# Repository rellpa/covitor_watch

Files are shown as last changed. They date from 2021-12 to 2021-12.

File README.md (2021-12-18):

# 🔥 CoViTor Watch 🔥
### <i>#Final project of Embedded System Design</i>
- CoViToR Watch App created using Android Studio with Java

⌚⌚⌚⌚⌚

Smartwatch system, made for COVID-19 symptoms monitoring where you can monitor your current health condition such as temperature, oxygen saturation, and heart rate. So when there are any symptoms of COVID-19 you can take the appropriate action.

Stay healthy and keep wearing your mask!! 😷

<p align="left">
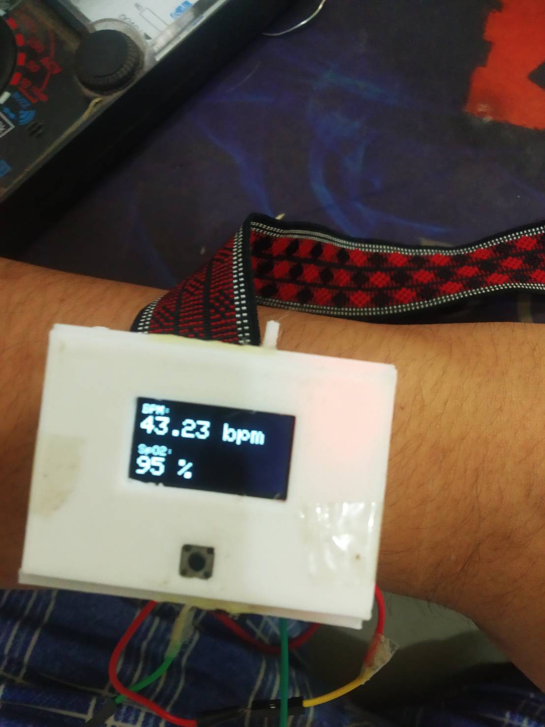
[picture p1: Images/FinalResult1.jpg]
  
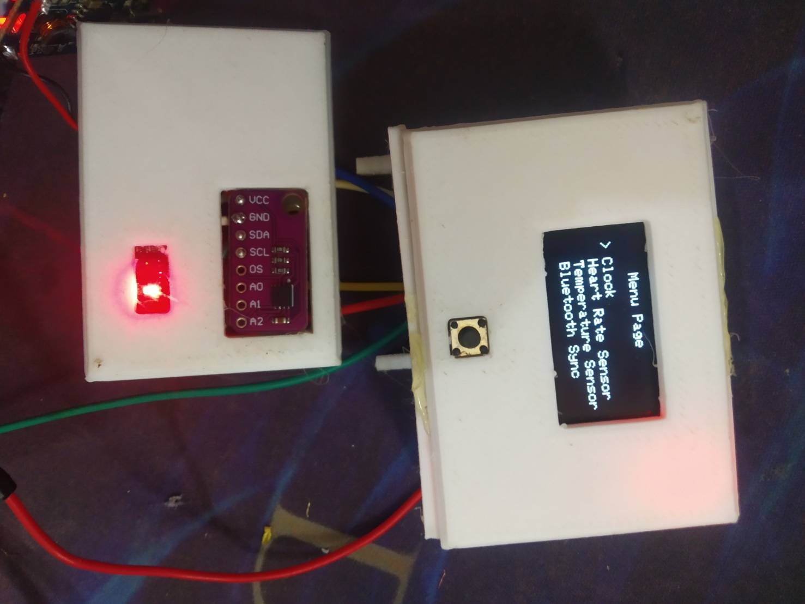
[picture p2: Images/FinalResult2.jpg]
  
</p>

#

## 🔌 How to make this embedded system.
### List of component
- Microcontroller Wemos D1 (NodeMCU ESP32 wifi+BL)
- Watch Sized SSD1306 0.96 inch OLED LCD I2C
- Enclosure Smartwatch 3D print
- A button
- Cables
- Battery 503030 3.7V mini 500mAh
- Charging controller TP4056
- 2.8cm / 28mm watch strap with 3cm spring bar
- MAX30205 Temperature Sensor 0°C to 50°C (Human Range)
- MAX30100 Heartrate and Oxymeter Sensor
- DS1307 + 24c32 Module IIC precision Real Time Clock(RTC) for Arduino (+CR2032 Battery)

Budget for component on december 2021 = Rp. 321.400 (~ US $22,34)

### Hardware Diagram
<p align="left">
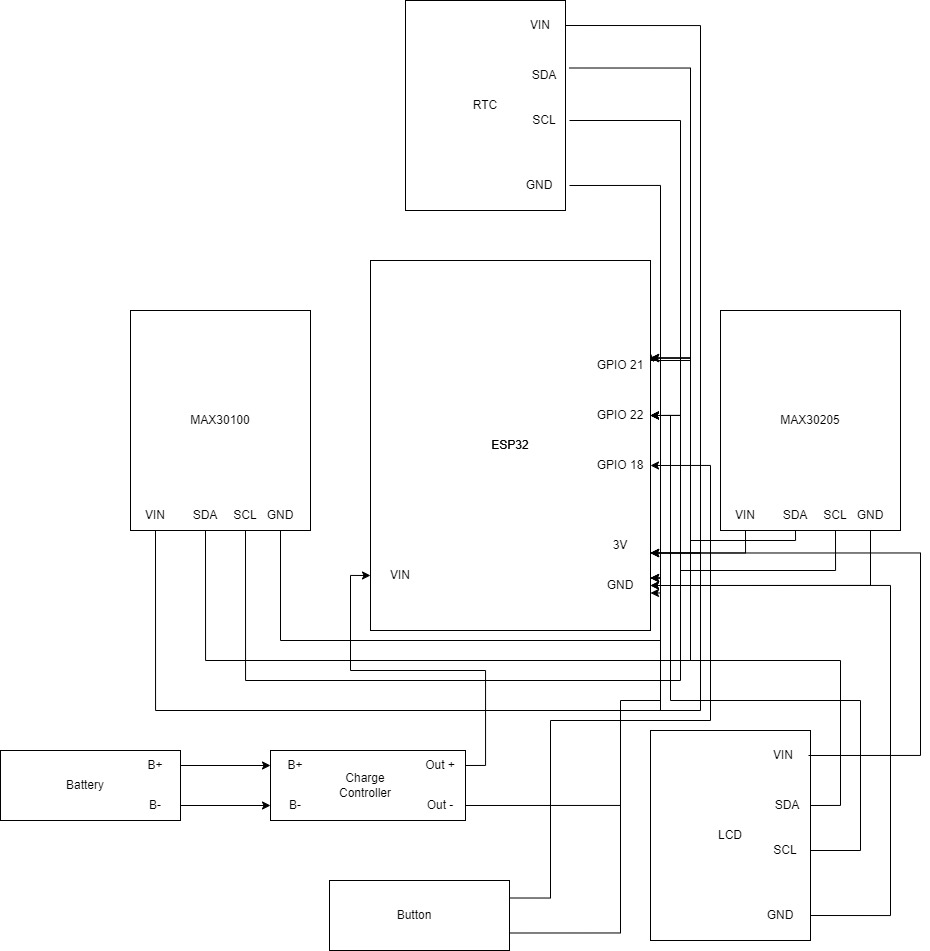
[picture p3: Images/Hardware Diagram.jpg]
  
</p>

- <i>I2C module (MAX30100, MAX30205, DS1307, SSD1306)</i>
- SCL -> GPIO 22 (ESP32)
- SDA -> GPIO 21 (ESP32)
- Vin -> 3.3V (ESP32)
- GND -> GND (ESP32)

### Architecture Diagram
<p align="left">
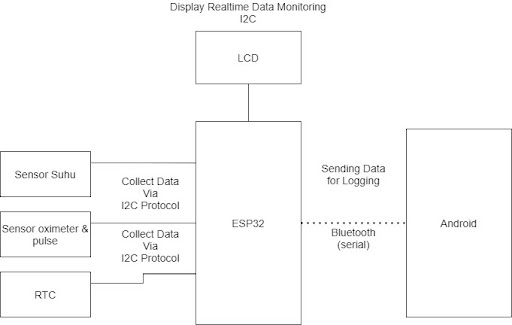
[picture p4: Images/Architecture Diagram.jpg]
  
</p>

### MVC
<p align="left">
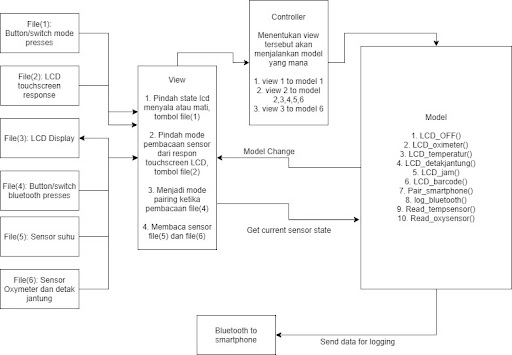
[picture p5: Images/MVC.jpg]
  
</p>

#

## 🤖 Arduino
We're using ESP32 Wemos D1 Mini

For some other controllers including controllers which are not ESP family, may need some more configuration.

How to use this code
- Install and open arduino IDE
- Install esp32 board family, using board manager
- Clone and open "CovitorWatch.ino"
- Flash to esp32 controller using available port
- Done

Features:
- Motion detector with one button
- Menu page
- Clock page
- Heart Rate, Blood Saturation, and Temparature readings page.
- Bluetooth Sync Mode
- QR code
- Blank screen for power saving

Library:
- BluetoothSerial
- Adafruit_GFX
- Adafruit_SSD1306
- RTClib
- MAX30100_PulseOximeter
- Protocentral_MAX30205
- OneButton

### <i>*How to use</i>
- double click to OK and go to menu page.
- triple click on any page to go QR code page.
- Long click on any page to go blank screen, use double click to exit blank screen mode.

### <i>*For improvement</i>
When using bluetooth serial, the heart rate and oximeter data are not updating because a problem. On ESP32, somehow the library of MAX30100 and bluetooth serial can't work together. This is because if you use a serial bluetooth module, it will slow down the looping time of the routine. The MAX30100 library is set to update data with a sampling frequency of 100Hz, so it should take less than 10ms to call this function. For that, use a newer module such as MAX30102, to get improvement functionality.

#

## 🚨 3D Enclosure
To create the 3D enclosure, we used 3D print Creality Ender-3 Pro
with printer settings:

- Slicer App: PrusaSlicer 2.3.1
- Print Setting: 0.28mm (use 0.16mm or 0.20mm for more tidy looks)
- Filament: PLA (please use ABS or something stronger than PLA if you want more rigid)
- Infill: 15%
- Supports: None
- Duration for all parts: 1 hour (0.28mm quality)

<i>*For watch strap, please using 28mm size with 30mm Spring Bar</i>

#

Full enclosure:
<p align="left">
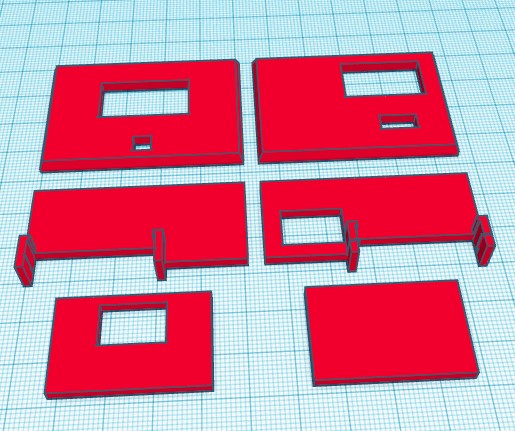
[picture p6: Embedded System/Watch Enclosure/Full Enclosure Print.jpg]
  
</p>

Component arrangement:
<p align="left">
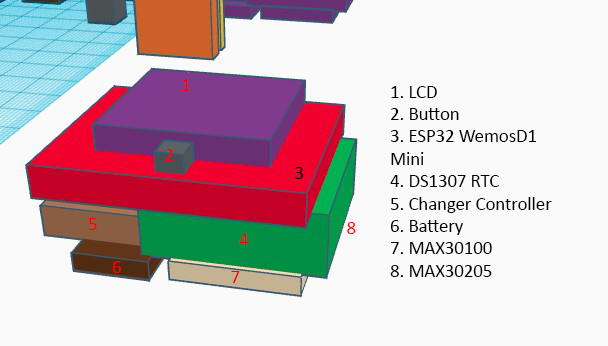
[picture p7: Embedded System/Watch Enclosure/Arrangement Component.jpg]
  
</p>

#

## 📱 CoViTor Watch APP
<i>!!This app created using android studio and java languange</i>

### How this app work?
In our embedded system (CoViTor Smartwatch), we use bluetooth serial (Bluetooth 2). So we can communicate using Bluetooth Socket from android. Basically, using bluetooth serial communication to an embedded system is to use an outputstream to send data and an inputstream to get data. We just need to manage how the two work together to form a useful application. For the monitoring sequence, we use a query method when needed so that the embedded system does not always send data. First the application will send a command that the embedded system knows what to send. After that the embedded system will send sensor data to the application, and the application will parse the byte data into strings or integers for further processing.

<p align="left">
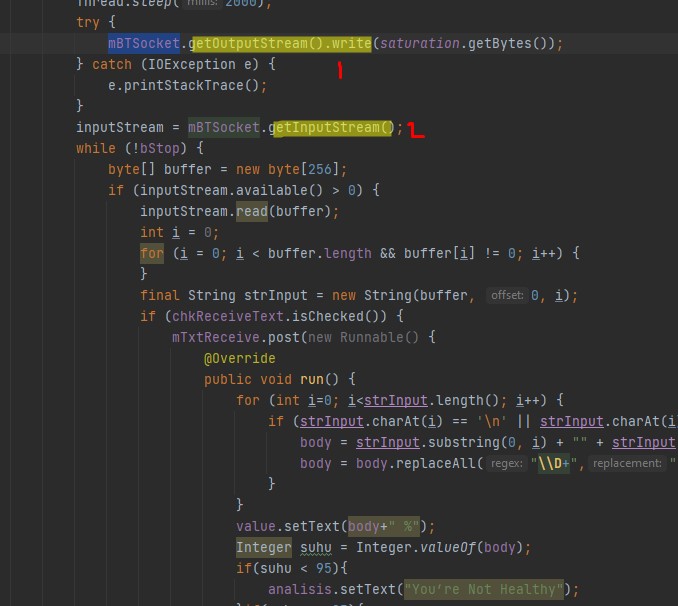
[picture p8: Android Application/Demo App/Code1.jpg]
  
</p>

### How to use this project ?
For demo purpose (if you use same firmware as this embbeded system) you can install APK app on your android phone.

If you want reverse engineering this project app:
1. Install android studio on your computer
2. Clone "CovitorWatchEmbedded" folder
3. Import that folder to android studio
4. Sync graddle (if necessary), and you success to import this app and ready to reverse engineering to your needs!

<i>if need help, feel free to contact us! MatthewBrandon21 / rellpa.</i>

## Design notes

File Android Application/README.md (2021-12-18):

# CoViTor Watch APP
### <i>!!This app created using android studio and java languange</i>

#

## How this app work?
In our embedded system (CoViTor Smartwatch), we use bluetooth serial (Bluetooth 2). So we can communicate using Bluetooth Socket from android. Basically, using bluetooth serial communication to an embedded system is to use an outputstream to send data and an inputstream to get data. We just need to manage how the two work together to form a useful application. For the monitoring sequence, we use a query method when needed so that the embedded system does not always send data. First the application will send a command that the embedded system knows what to send. After that the embedded system will send sensor data to the application, and the application will parse the byte data into strings or integers for further processing.

<p align="left">
  
</p>
#

## How to use this project ?
For demo purpose (if you use same firmware as this embbeded system) you can install APK app on your android phone.

If you want reverse engineering this project app:
1. Install android studio on your computer
2. Clone "CovitorWatchEmbedded" folder
3. Import that folder to android studio
4. Sync graddle (if necessary), and you success to import this app and ready to reverse engineering to your needs!

<i>if need help, feel free to contact us! MatthewBrandon21 / rellpa.</i>

#

Some screenshoot of this app:
<p align="left">
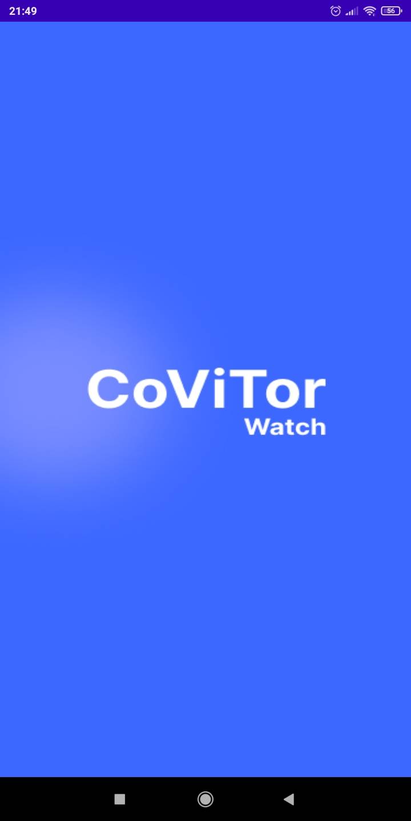
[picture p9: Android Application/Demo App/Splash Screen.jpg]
  
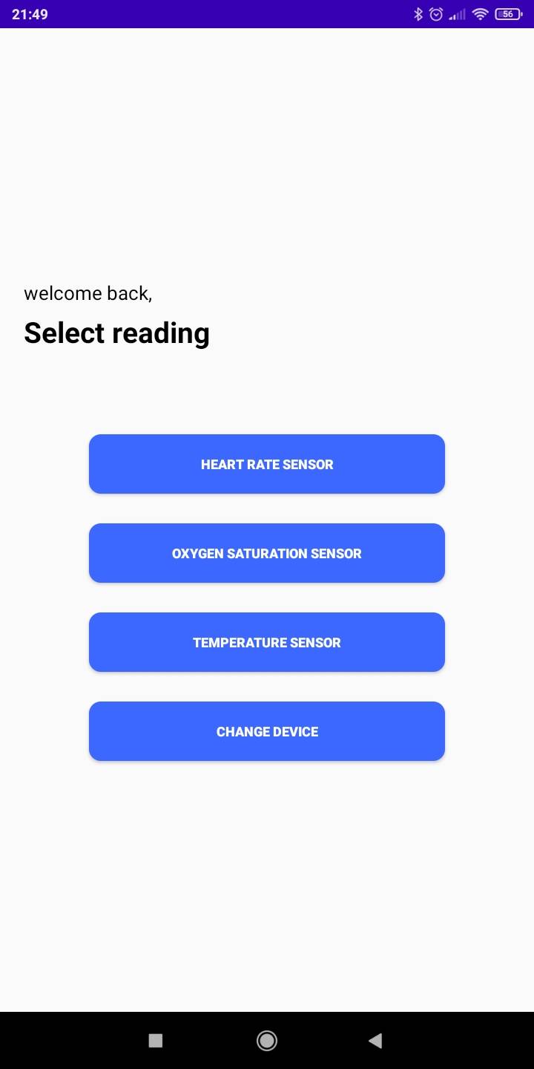
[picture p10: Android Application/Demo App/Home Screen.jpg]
  
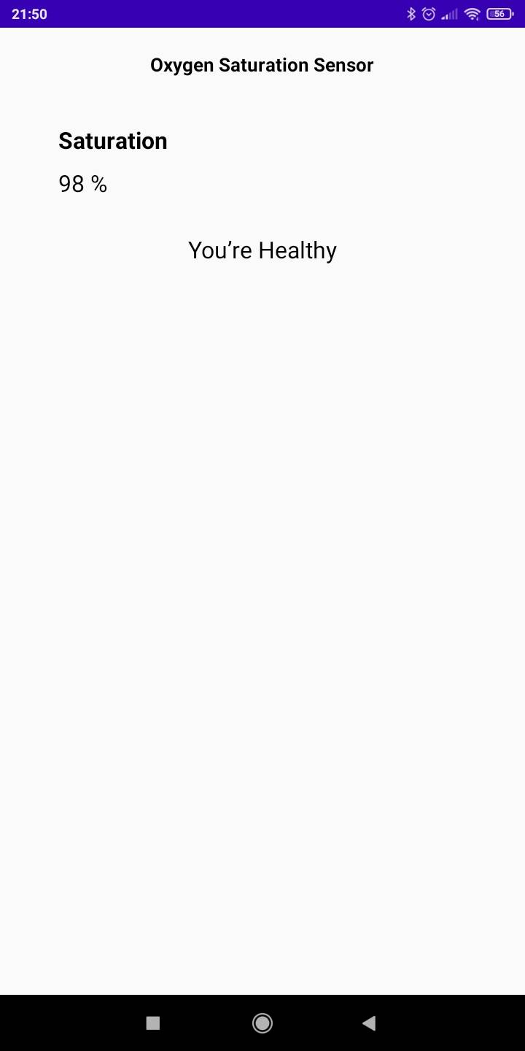
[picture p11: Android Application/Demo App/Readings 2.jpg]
  
</p>
<i>For full screenshoot you can see in "Demo App" folder.</i>

#

### <i>*For improvement<i/>
Maybe UI/UX design can be more prettier. FYI we use figma to design UI of this app and linear layout in xml layout.

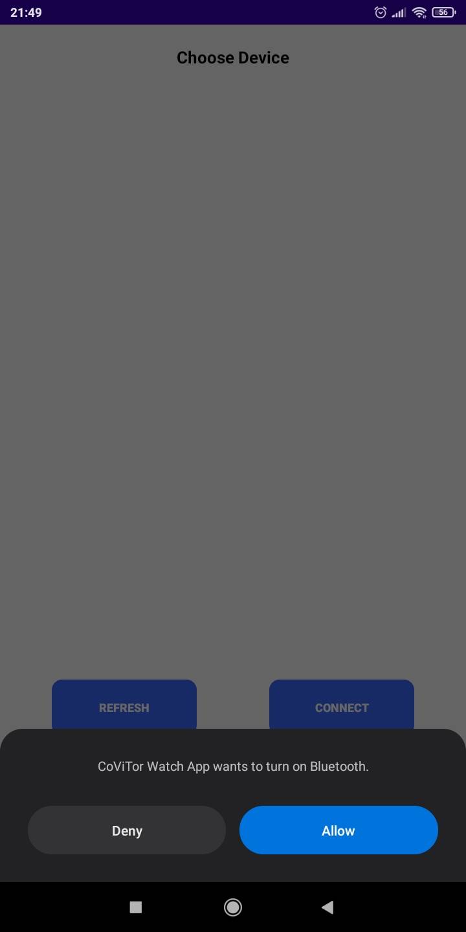
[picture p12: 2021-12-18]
Android Application/Demo App/Bluetooth Activation.jpg

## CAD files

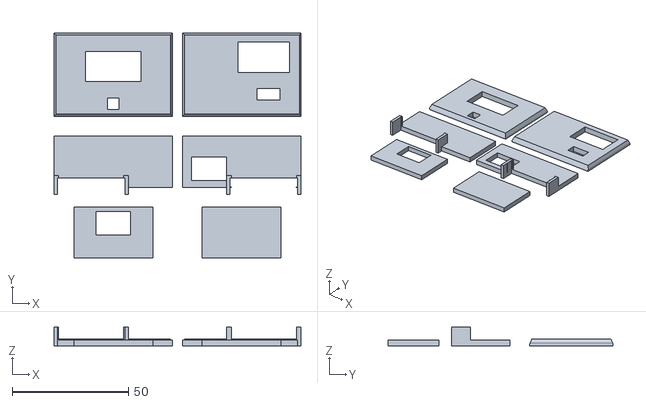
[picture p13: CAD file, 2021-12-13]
Embedded System/Watch Enclosure/Full Enclosure Print.stl
106.2 x 97.0 x 8.00

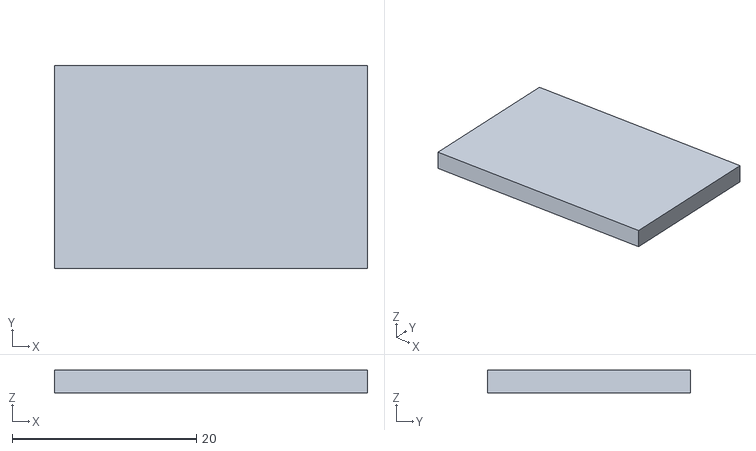
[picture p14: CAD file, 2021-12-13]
Embedded System/Watch Enclosure/Body2.stl
34.0 x 22.0 x 2.50

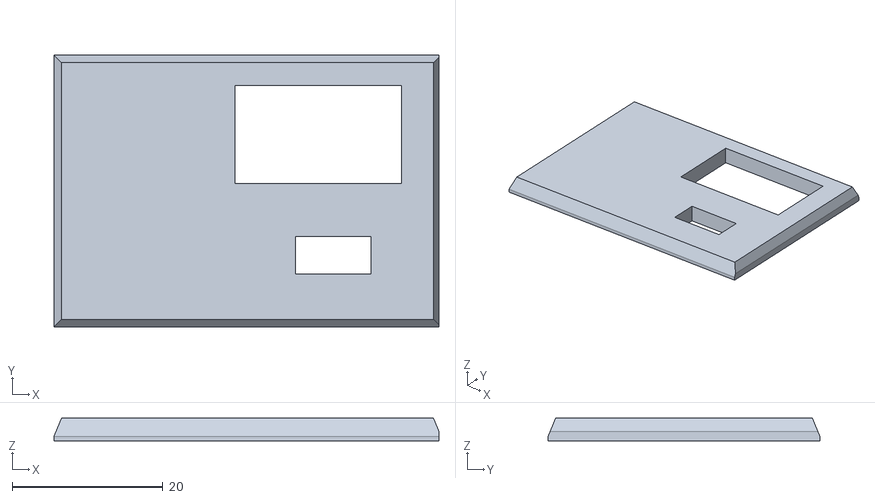
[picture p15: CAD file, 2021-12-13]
Embedded System/Watch Enclosure/Bottom.stl
51.0 x 36.0 x 3.00

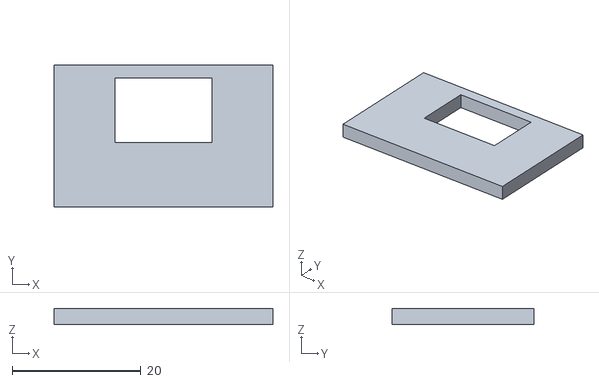
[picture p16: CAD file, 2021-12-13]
Embedded System/Watch Enclosure/Body1.stl
34.0 x 22.0 x 2.50

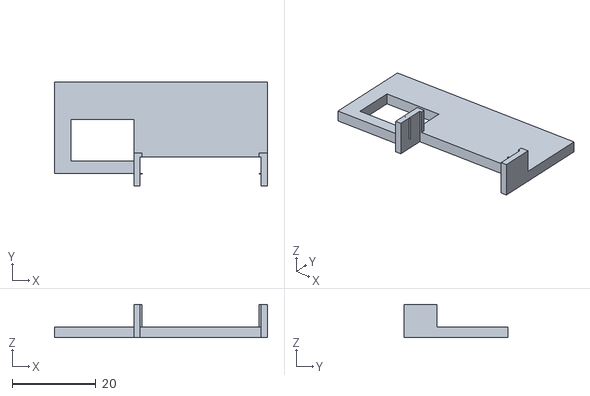
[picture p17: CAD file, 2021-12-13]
Embedded System/Watch Enclosure/Body4.stl
51.0 x 25.0 x 8.00

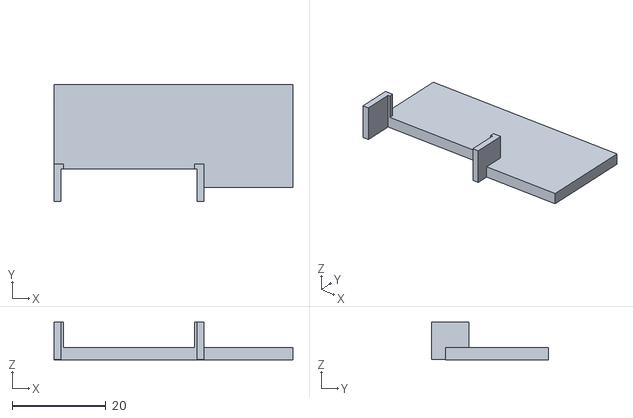
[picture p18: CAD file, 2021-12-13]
Embedded System/Watch Enclosure/Body3.stl
51.0 x 25.0 x 8.00

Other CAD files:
Embedded System/Watch Enclosure/Top.stl

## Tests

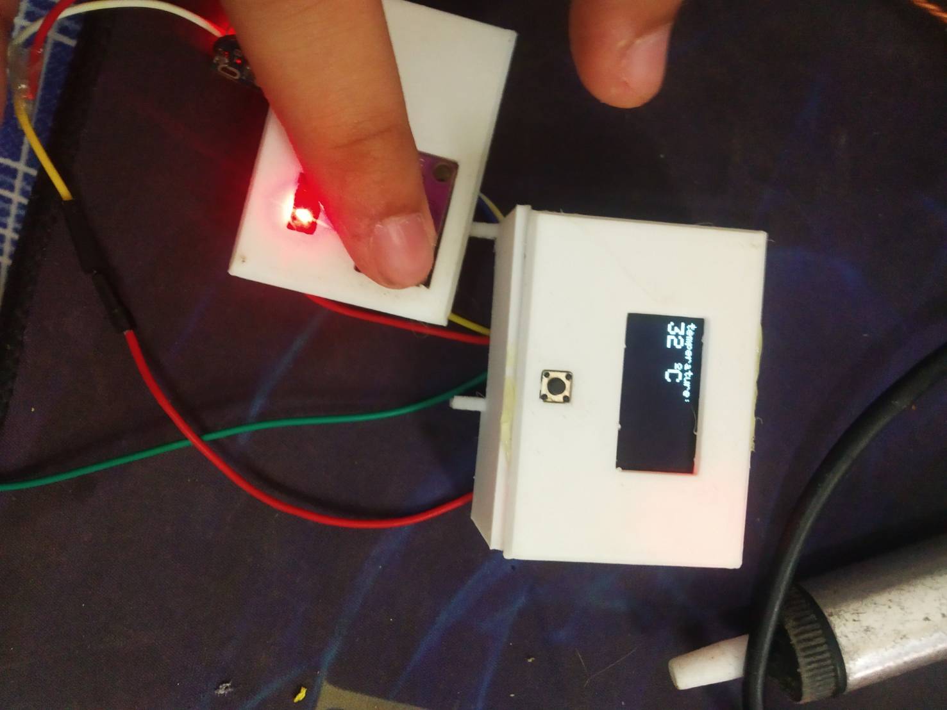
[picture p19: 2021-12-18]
Images/FinalResult4.jpg

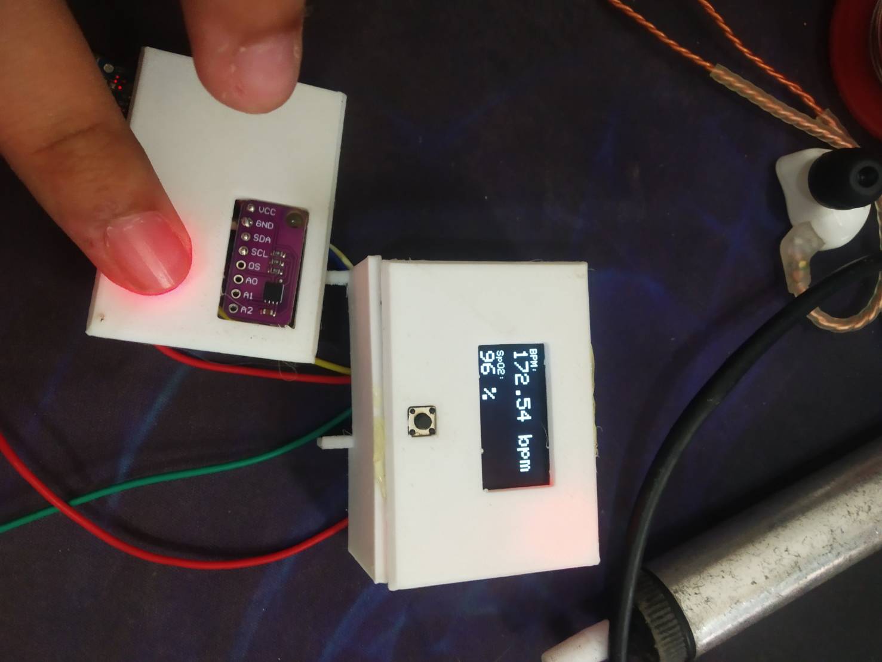
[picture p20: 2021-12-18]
Images/FinalResult3.jpg

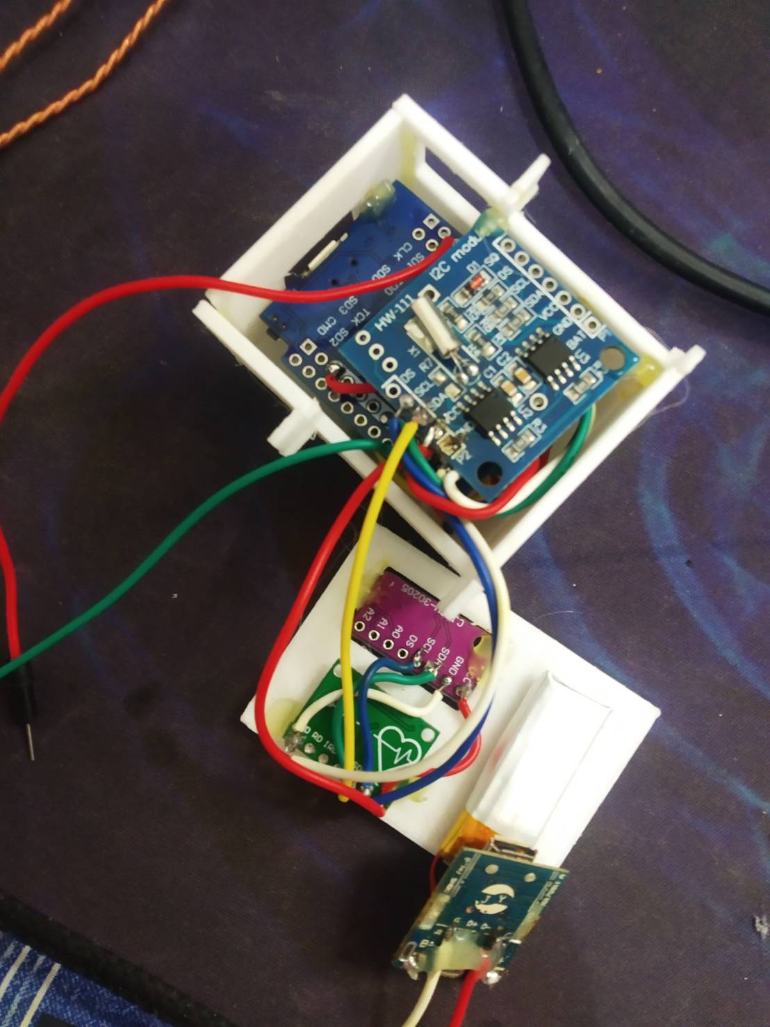
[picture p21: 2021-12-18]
Images/FinalResult5.jpg

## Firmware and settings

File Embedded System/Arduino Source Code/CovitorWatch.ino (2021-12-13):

#include <Wire.h>
#include "BluetoothSerial.h"
#include <Adafruit_GFX.h>
#include <Adafruit_SSD1306.h>
#include "RTClib.h"
#include "MAX30100_PulseOximeter.h"
#include "Protocentral_MAX30205.h"
#include "OneButton.h"

#define REPORTING_PERIOD_MS 1000
#define SCREEN_WIDTH 128
#define SCREEN_HEIGHT 64

Adafruit_SSD1306 display(SCREEN_WIDTH, SCREEN_HEIGHT, &Wire, -1);

BluetoothSerial SerialBT;
RTC_DS1307 RTC;
PulseOximeter pox;
MAX30205 tempSensor;
uint32_t tsLastReport = 0;
long int data;
int buttonPin = 18;
OneButton button(buttonPin, true);
uint8_t btn_prev;
int Vdatatemp = 12; 
int Vdataheart = 12; 
int Vdatasaturation = 12; 
long int heartratecommand = 20;
long int oxygensaturationcommand = 21;
long int temperaturecommand = 22;
long int temperatureid = 23;
long int heartrateid = 24;
long int saturationid = 25;
int page = 2; //clock = 1, heart rate = 2, temperature = 3, bluetooth sycn = 4, QR Code = 5, turn off display = 6, menu = 7
int old_page = page;
int bt = 0;
int bluetoothcommand = 0;
int menuItem = 1; //clock = 1, heart rate = 2, temperature = 3, bluetooth sycn = 4 ,QR Code = 5, turn off display = 6, restart device = 7
RTC_DS1307 DS1307_RTC;

static const uint8_t image_data_qrkekl[1024] = {
  0xff, 0xff, 0xff, 0xff, 0xff, 0xff, 0xff, 0xff, 0xff, 0xff, 0xff, 0xff, 0xff, 0xff, 0xff, 0xff, 
  0xff, 0xff, 0xff, 0xff, 0xff, 0xff, 0xff, 0xff, 0xff, 0xff, 0xff, 0xff, 0xff, 0xff, 0xff, 0xff, 
  0xff, 0xff, 0xff, 0xff, 0xff, 0xff, 0xff, 0xff, 0xff, 0xff, 0xff, 0xff, 0xff, 0xff, 0xff, 0xff, 
  0xff, 0xff, 0xff, 0xff, 0xff, 0xff, 0xff, 0xff, 0xff, 0xff, 0xff, 0xff, 0xff, 0xff, 0xff, 0xff, 
  0xff, 0xff, 0xff, 0xff, 0xf0, 0x00, 0x0c, 0x3f, 0xe7, 0x30, 0x00, 0x0f, 0xff, 0xff, 0xff, 0xff, 
  0xff, 0xff, 0xff, 0xff, 0xf0, 0x00, 0x0c, 0x3f, 0xe7, 0x30, 0x00, 0x0f, 0xff, 0xff, 0xff, 0xff, 
  0xff, 0xff, 0xff, 0xff, 0xf3, 0xff, 0x8f, 0xff, 0xff, 0x33, 0xff, 0xcf, 0xff, 0xff, 0xff, 0xff, 
  0xff, 0xff, 0xff, 0xff, 0xf3, 0xff, 0x8f, 0xff, 0xff, 0x33, 0xff, 0xcf, 0xff, 0xff, 0xff, 0xff, 
  0xff, 0xff, 0xff, 0xff, 0xf3, 0x81, 0x8c, 0xf8, 0x1f, 0x33, 0x81, 0xcf, 0xff, 0xff, 0xff, 0xff, 
  0xff, 0xff, 0xff, 0xff, 0xf3, 0x01, 0x8c, 0xf0, 0x1f, 0x33, 0x81, 0xcf, 0xff, 0xff, 0xff, 0xff, 
  0xff, 0xff, 0xff, 0xff, 0xf3, 0x01, 0x8c, 0xf0, 0x0f, 0x33, 0x81, 0xcf, 0xff, 0xff, 0xff, 0xff, 
  0xff, 0xff, 0xff, 0xff, 0xf3, 0x01, 0x8c, 0x39, 0x87, 0xf3, 0x81, 0xcf, 0xff, 0xff, 0xff, 0xff, 
  0xff, 0xff, 0xff, 0xff, 0xf3, 0x01, 0x8c, 0x31, 0x83, 0xf3, 0x81, 0xcf, 0xff, 0xff, 0xff, 0xff, 
  0xff, 0xff, 0xff, 0xff, 0xf3, 0x01, 0x8c, 0x01, 0xe0, 0x33, 0x81, 0xcf, 0xff, 0xff, 0xff, 0xff, 
  0xff, 0xff, 0xff, 0xff, 0xf3, 0x01, 0x8c, 0x01, 0xe0, 0x33, 0x81, 0xcf, 0xff, 0xff, 0xff, 0xff, 
  0xff, 0xff, 0xff, 0xff, 0xf3, 0xff, 0x8f, 0x3e, 0x07, 0xf3, 0xff, 0xcf, 0xff, 0xff, 0xff, 0xff, 
  0xff, 0xff, 0xff, 0xff, 0xf3, 0xff, 0x8f, 0x3e, 0x07, 0xf3, 0xff, 0xcf, 0xff, 0xff, 0xff, 0xff, 
  0xff, 0xff, 0xff, 0xff, 0xf0, 0x00, 0x0c, 0xce, 0x67, 0x30, 0x00, 0x0f, 0xff, 0xff, 0xff, 0xff, 
  0xff, 0xff, 0xff, 0xff, 0xf0, 0x00, 0x0c, 0xc6, 0x67, 0x30, 0x00, 0x0f, 0xff, 0xff, 0xff, 0xff, 
  0xff, 0xff, 0xff, 0xff, 0xf0, 0x00, 0x1c, 0xc6, 0xf3, 0x78, 0x00, 0x1f, 0xff, 0xff, 0xff, 0xff, 
  0xff, 0xff, 0xff, 0xff, 0xff, 0xff, 0xff, 0x31, 0xf8, 0xff, 0xff, 0xff, 0xff, 0xff, 0xff, 0xff, 
  0xff, 0xff, 0xff, 0xff, 0xff, 0xff, 0xff, 0x39, 0xfc, 0xff, 0xff, 0xff, 0xff, 0xff, 0xff, 0xff, 
  0xff, 0xff, 0xff, 0xff, 0xf0, 0x07, 0x8c, 0xff, 0xff, 0xcf, 0x81, 0xcf, 0xff, 0xff, 0xff, 0xff, 
  0xff, 0xff, 0xff, 0xff, 0xf0, 0x07, 0x8c, 0xff, 0xff, 0xcf, 0x81, 0xcf, 0xff, 0xff, 0xff, 0xff, 
  0xff, 0xff, 0xff, 0xff, 0xfc, 0x18, 0x7f, 0x3f, 0x9f, 0x3c, 0x7e, 0x3f, 0xff, 0xff, 0xff, 0xff, 
  0xff, 0xff, 0xff, 0xff, 0xfc, 0x38, 0x7f, 0x3f, 0x9f, 0x3c, 0x7e, 0x3f, 0xff, 0xff, 0xff, 0xff, 
  0xff, 0xff, 0xff, 0xff, 0xf3, 0x01, 0x80, 0xff, 0x9f, 0xfc, 0x7f, 0xff, 0xff, 0xff, 0xff, 0xff, 
  0xff, 0xff, 0xff, 0xff, 0xf3, 0x01, 0x80, 0xff, 0x9f, 0xfc, 0x7f, 0xff, 0xff, 0xff, 0xff, 0xff, 
  0xff, 0xff, 0xff, 0xff, 0xf3, 0x1e, 0x60, 0xf8, 0x01, 0xcc, 0x01, 0xff, 0xff, 0xff, 0xff, 0xff, 
  0xff, 0xff, 0xff, 0xff, 0xf3, 0x3e, 0x70, 0xf0, 0x00, 0xcc, 0x01, 0xff, 0xff, 0xff, 0xff, 0xff, 
  0xff, 0xff, 0xff, 0xff, 0xf3, 0x1e, 0x70, 0xf0, 0x01, 0xcc, 0x00, 0xff, 0xff, 0xff, 0xff, 0xff, 
  0xff, 0xff, 0xff, 0xff, 0xf0, 0xe7, 0x8c, 0x39, 0xff, 0xc3, 0x98, 0x0f, 0xff, 0xff, 0xff, 0xff, 
  0xff, 0xff, 0xff, 0xff, 0xf0, 0xe7, 0x9c, 0x31, 0xff, 0xc3, 0x98, 0x0f, 0xff, 0xff, 0xff, 0xff, 
  0xff, 0xff, 0xff, 0xff, 0xff, 0xf8, 0x7f, 0x01, 0x80, 0xc0, 0x1f, 0xcf, 0xff, 0xff, 0xff, 0xff, 
  0xff, 0xff, 0xff, 0xff, 0xff, 0xf8, 0x7f, 0x01, 0x80, 0xc0, 0x1f, 0xcf, 0xff, 0xff, 0xff, 0xff, 
  0xff, 0xff, 0xff, 0xff, 0xfc, 0x06, 0x00, 0x06, 0x63, 0xf1, 0x18, 0x3f, 0xff, 0xff, 0xff, 0xff, 
  0xff, 0xff, 0xff, 0xff, 0xfc, 0x06, 0x00, 0x06, 0x67, 0xf3, 0x98, 0x3f, 0xff, 0xff, 0xff, 0xff, 
  0xff, 0xff, 0xff, 0xff, 0xf3, 0x1e, 0x38, 0x1e, 0x19, 0xcc, 0x1f, 0xdf, 0xff, 0xff, 0xff, 0xff, 
  0xff, 0xff, 0xff, 0xff, 0xf3, 0x1e, 0x7c, 0x3e, 0x18, 0xcc, 0x1f, 0xcf, 0xff, 0xff, 0xff, 0xff, 
  0xff, 0xff, 0xff, 0xff, 0xf3, 0x9e, 0x78, 0x1e, 0x18, 0xcc, 0x1f, 0x8f, 0xff, 0xff, 0xff, 0xff, 
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
};

void onBeatDetected()
{
    Serial.println("Beat!");
}

void page_heartratesensor(){
    display.clearDisplay();
    // display BPM
    display.setTextSize(1);
    display.setCursor(0,0);
    display.print("BPM: ");
    display.setTextSize(2);
    display.setCursor(0,10);
    display.print(String(pox.getHeartRate()));
    display.print(" ");
    display.setTextSize(2);
    display.print("bpm");
    // display SPO2
    display.setTextSize(1);
    display.setCursor(0, 35);
    display.print("SpO2: ");
    display.setTextSize(2);
    display.setCursor(0, 45);
    display.print(String(pox.getSpO2()));
    display.print(" %"); 
    display.display();
}
void page_temperaturesensor(){
    display.clearDisplay();
    // display temperature
    display.setTextSize(1);
    display.setCursor(0,0);
    display.print("temperature: ");
    display.setTextSize(2);
    display.setCursor(0,10);
    display.print(String(Vdatatemp));
    display.print(" ");
    display.setTextSize(1);
    display.cp437(true);
    display.write(167);
    display.setTextSize(2);
    display.print("C");
    display.display();
}
void page_qrcode(){
    display.clearDisplay();
    display.drawBitmap(0, 0, image_data_qrkekl, 128, 64, 1);
    display.display();
}
void page_menu(){
    display.clearDisplay();
    display.setTextSize(1);
    display.setTextColor(WHITE);
    display.setCursor(30, 0);
    display.print("Menu Page");
    if (menuItem == 1) {
      display.setCursor(5, 17);
      display.setTextColor(WHITE);
      display.print("> Clock");
    } else {
      display.setCursor(5, 17);
      display.setTextColor(WHITE);
      display.print("  Clock");
    }

    if (menuItem == 2) {
      display.setCursor(5, 27);
      display.setTextColor(WHITE);
      display.print("> Heart Rate Sensor");
    } else {
      display.setCursor(5, 27);
      display.setTextColor(WHITE);
      display.print("  Heart Rate Sensor");
    }

    if (menuItem == 3) {
      display.setCursor(5, 37);
      display.setTextColor(WHITE);
      display.print("> Temperature Sensor");
    } else {
      display.setCursor(5, 37);
      display.setTextColor(WHITE);
      display.print("  Temperature Sensor");
    }

    if (menuItem == 4) {
      display.setCursor(5, 47);
      display.setTextColor(WHITE);
      display.print("> Bluetooth Sync");
    } else {
      display.setCursor(5, 47);
      display.setTextColor(WHITE);
      display.print("  Bluetooth Sync");
    }
    display.display();
}

void page_clock(){
    display.clearDisplay();
    display.setTextSize(1);
    DateTime now = RTC.now();
    display.setCursor(40,30);
    display.setTextSize(1);
    display.print(now.day());
    display.print('/');
    display.print(now.month());
    display.print('/');
    display.print(now.year());
    display.print(' ');
    display.setCursor(40, 40);
    display.print(now.hour());
    display.print(':');
    display.print(now.minute());
    display.print(':');
    display.print(now.second());
    display.setTextSize(1);
    display.setTextColor(WHITE);
    display.setCursor(10, 4);
    // Display static text
    display.println("Digital Clock");
    display.display(); 
}

void page_bluetooth(){
    if(bluetoothcommand == 0){
          display.clearDisplay();
          // display temperature
          display.setTextSize(1);
          display.setCursor(0,0);
          display.print("Bluetooth Pairing");
          display.display();
    }
    if(bluetoothcommand == 1){
          display.clearDisplay();
          display.setTextSize(1);
          display.setCursor(0,0);
          display.print("Bluetooth Sync");
          display.setTextSize(1);
          display.setCursor(0, 35);
          display.print("Heart Rate: ");
          display.setTextSize(2);
          display.setCursor(0, 45);
          display.print(String(Vdataheart));
          display.print(" bpm"); 
          display.display();
    }
    if(bluetoothcommand == 2){
          display.clearDisplay();
          display.setTextSize(1);
          display.setCursor(0,0);
          display.print("Bluetooth Sync");
          display.setTextSize(1);
          display.setCursor(0, 35);
          display.print("Saturation: ");
          display.setTextSize(2);
          display.setCursor(0, 45);
          display.print(String(Vdatasaturation));
          display.print(" %"); 
          display.display();
    }
    if(bluetoothcommand == 3){
          display.clearDisplay();
          display.setTextSize(1);
          display.setCursor(0,0);
          display.print("Bluetooth Sync");
          display.setTextSize(1);
          display.setCursor(0, 35);
          display.print("Temperature: ");
          display.setTextSize(2);
          display.setCursor(0, 45);
          Vdatatemp = tempSensor.getTemperature();
          display.print(String(Vdatatemp));
          display.setTextSize(1);
          display.cp437(true);
          display.write(167);
          display.setTextSize(2);
          display.print("C"); 
          display.display();
    }
    if(SerialBT.available()>0){
      data = SerialBT.parseInt();
        if (data == heartratecommand){
          Serial.println("Heart Rate Mode");
          bluetoothcommand = 1;
          data = 0; 
        } if ( data == oxygensaturationcommand){
          Serial.println("Oxygen Saturation Mode");
          bluetoothcommand = 2;
          data = 0;
        } if ( data == temperaturecommand){
          Serial.println("Temperature Mode");
          bluetoothcommand = 3;
          data = 0;
        }
        if ( data == temperatureid){
          Vdatatemp = tempSensor.getTemperature();
          Serial.print("data: "); 
          Serial.println(Vdatatemp);
          Serial.println("________________");
          SerialBT.println(Vdatatemp);
          data = 0;
        }
        if ( data == heartrateid){
          Serial.print("data: "); 
          Serial.println(Vdataheart);
          Serial.println("________________");
          SerialBT.println(Vdataheart);
          data = 0;
        }
        if ( data == saturationid){
          Serial.print("data: "); 
          Serial.println(Vdatasaturation);
          Serial.println("________________");
          SerialBT.println(Vdatasaturation);
          data = 0;
        }
        delay(1000);
    } 
}

void setup(){ 
     Serial.begin(115200); 
           if (!pox.begin()) {
          Serial.println("FAILED");
          for(;;);
      } else {
          Serial.println("SUCCESS");
      }
      pox.setIRLedCurrent(MAX30100_LED_CURR_7_6MA);
      pox.setOnBeatDetectedCallback(onBeatDetected);
     Wire.begin();
     if(!display.begin(SSD1306_SWITCHCAPVCC, 0x3C)){
        Serial.println(F("SSD1306 allocation failed"));
        for(;;);
     }
     while(!tempSensor.scanAvailableSensors()){
        Serial.println("Couldn't find the temperature sensor, please connect the sensor." );
        delay(3000);
      }
    tempSensor.begin(); 
    if (! RTC.begin()) {
      Serial.println("RTC TIDAK TERBACA");
      while (1);
    }
    if (! RTC.isrunning()) {
      Serial.println("RTC is NOT running!");
      RTC.adjust(DateTime(F(__DATE__), F(__TIME__)));//update rtc dari waktu komputer
    }
    display.clearDisplay();
    display.setTextColor(WHITE);
    pinMode(buttonPin, INPUT_PULLUP);
    button.attachClick(changeMenuItem);
    button.attachDoubleClick(doubleClick);
    button.attachMultiClick(QRpage);
    button.attachLongPressStop(Idle);
}

void loop(){
  button.tick();
  if ( page == 1){
    page_clock();
  }
  if ( page == 2){
    pox.update();
    if (millis() - tsLastReport > REPORTING_PERIOD_MS) {
      Vdataheart = pox.getHeartRate();
      Vdatasaturation = pox.getSpO2();
      page_heartratesensor();
      tsLastReport = millis();
    }
  }
  if ( page == 3){
    if (millis() - tsLastReport > REPORTING_PERIOD_MS) {
      Vdatatemp = tempSensor.getTemperature();
      if(Vdatatemp != 0){
        page_temperaturesensor();
      }
      tsLastReport = millis();
    }
  }
  if ( page == 4){
    page_bluetooth();
  }
  if ( page == 5){
    page_qrcode();
  }
  if ( page == 6){
    display.ssd1306_command(SSD1306_DISPLAYOFF);
  }
  if ( page == 7){
    page_menu();
  }
}

void doubleClick()
{
      if (page == 6){
        display.ssd1306_command(SSD1306_DISPLAYON);
      }
      if (page == 7){
        if (page == 7 && menuItem == 1) {
          old_page = page;
          page = 1;
        } else if (page == 7 && menuItem == 2) {
          old_page = page;
          page = 2;
          ESP.restart();
        } else if (page == 7 && menuItem == 3) {
          old_page = page;
          page = 3;
        } else if (page == 7 && menuItem == 4) {
          old_page = page;
          page = 4;
          SerialBT.begin("CovitorWatch");
          bt = 1;
        }
    }
    else if (page == 1 || page == 2 || page == 3 || page == 4 || page == 5 || page == 6 && bt == 0) {
      page = 7;
    } else if (page == 1 || page == 2 || page == 3 || page == 4 || page == 5 || page == 6 && bt == 1) {
      ESP.restart();
    }
}

void changeMenuItem()
{
    menuItem ++;
    if (menuItem > 4)menuItem = 1;
}

void QRpage()
{
    old_page = page;
    page = 5;
}

void Idle()
{
  if(page != 6){
      old_page = page;
      page = 6;
  }
}

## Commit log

2021-12-13 3D Enclosure upload
    [Body1.stl, Body2.stl, Body3.stl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]
2021-12-13 App and Arduino Code Update
2021-12-13 Add enclosure readme
2021-12-18 Update repository
    [Body1.stl, Body2.stl, Body3.stl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]
